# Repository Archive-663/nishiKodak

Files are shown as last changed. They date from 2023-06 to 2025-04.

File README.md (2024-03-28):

## Lot no. 006 | NishiKodak - The original digital stereoscopic wiggle lens

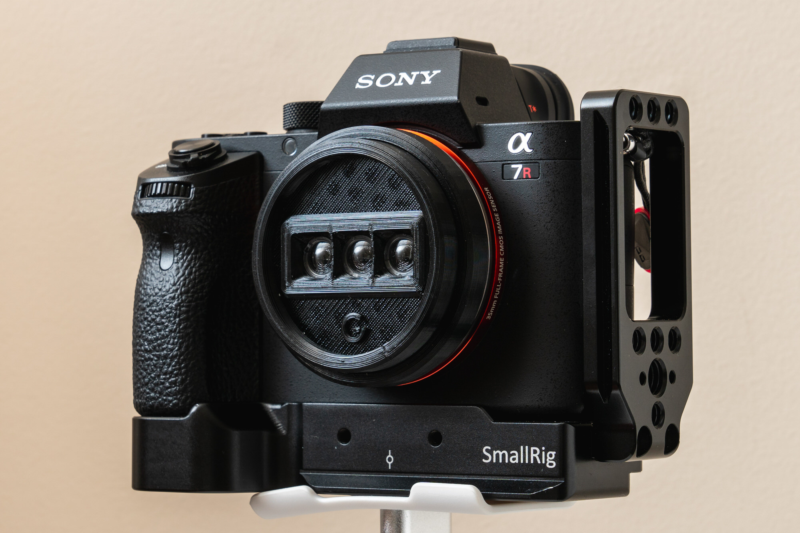
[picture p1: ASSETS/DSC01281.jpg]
sonyNishiKodak


### Features:
- Breech-lock mounting ring
- 30mm focal length
- Fixed ~f11 aperture
- Three individual images on one frame
- Available in: Canon EF, EF-S, FD, RF; Fuji X; Leica M; M42; Nikon F DX, F FX, Z FX; Sony E, FE

### What you'll need:
- Lots of M1.6 x 5mm pan head screws (PETG or ABS filament)
or
- Lots of M1.6 x 5mm self tapping screws (ABS filament)
- 1x M1.6 tap
- 3x Kodak Funsaver lenses (post-2015 expiration date. Kodak had a few lens changes in the Funsaver production lifetime. You'll need a recent Funsaver to make this work)

### What would be helpful:
- M1.4 drill bit
- M1.8/M2 drill bit

### Printing help:
I print with PETG because it's pretty easy to set up with and dial in. If you want to use something else, go for it. I'd stay away from PLA because it's not the best in heat and against solvents. 

Generally, my designs have chamfers on the print face of the STL.

Please view the printOrientation.3mf file for help with orienting the parts on the printer bed. 

### Assembly help:
I suggest drilling holds to their correct tap size before tapping. The M1.6 holes should be drilled out to 1.4mm then tapped with the M1.6 tap. The Rotator holes should be drilled out with an M2 or M1.8 drill bit.

When assembling the rotating assemblies use some synthetic grease similar to Super Lube PTFE or keycap lube to make the rotate function smoother.

Please view the _assembly.stp file for help in parts orientation. If you do not have a CAD program, <a href="https://www.freecad.org/downloads.php" target="_blank">download FreeCAD</a> to view the assembly file and better understand how it should assemble.

### Helpful videos:
- <a href="https://www.youtube.com/watch?v=ZdX-1SL8kYE" target="_blank">Old Print and Assembly Video</a>
- <a href="https://www.youtube.com/watch?v=JzHJL4l5Iv4" target="_blank">How to wigglegram</a>
- <a href="https://www.youtube.com/watch?v=mniP1P2PrpM" target="_blank">Kodak Funsaver Disassembly</a>
- <a href="https://www.youtube.com/watch?v=VX9ajfPWNos">How to use depth checker</a>

### Help support Archive 663 with a dontation or monthly sub



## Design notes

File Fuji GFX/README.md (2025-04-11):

## Lot no. 006 | NishiKodak - for Fuji GFX

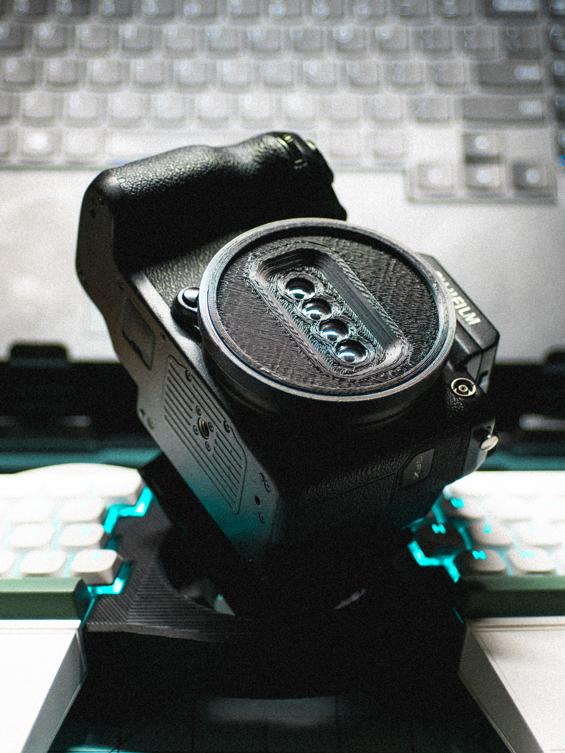
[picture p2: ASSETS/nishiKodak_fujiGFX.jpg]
nishiKodakforCanonEF


### Features:
- Breech-lock  mounting ring
- 30mm focal length
- Fixed ~f11 aperture
- Four individual images on one frame

### Compatibility Note:
Tested on Fuji GFX50s. Print the '_depthChecker.stl' to check for any intereference between the baffles and the shutter. To verify, with no lens mounted, fire the shutter. Make a note of where the mechanical shutter fires from. Mount the depth checker and visually inspect to verify the rear baffle doesn't interfere with the mechanical shutter. If you feel confident it doesn't fire the shutter to confirm. I recommend using the electronic shutter only to avoid any potential interfernce if you're not comfortable with firing the mechanical shutter. <a href="https://www.youtube.com/watch?v=VX9ajfPWNos" target="blank">How to use the Depth Checker</a>

### What you'll need:
- Lots of M1.6 x 5mm pan head screws (PETG or ABS filament)
  
  or

- Lots of M1.6 x 5mm self tapping screws (ABS filament)
- 1x M1.6 tap 
- 4x Kodak Funsaver lenses (post-2015 expiration date. Kodak had a few lens changes in the Funsaver production lifetime. You'll need a recent Funsaver to make this work)

### What would be helpful:
- M1.4 drill bit
- M1.8/M2 drill bit

### Printing help:
I print with PETG because it's pretty easy to set up with and dial in. If you want to use something else, go for it. I'd stay away from PLA because it's not the best in heat and against solvents. 

Generally, my designs have chamfers on the print face of the STL.

Please view the printOrientation.3mf file for help with orienting the parts on the printer bed. 

### Assembly help:
I suggest drilling holds to their correct tap size before tapping. The M1.6 holes should be drilled out to 1.4mm then tapped with the M1.6 tap.

When assembling the rotating assemblies use some synthetic grease similar to Super Lube PTFE or keycap lube to make the rotate function smoother.

Please view the _assembly.stp file for help in parts orientation. If you do not have a CAD program, <a href="https://www.freecad.org/downloads.php" target="_blank">download FreeCAD</a> to view the assembly file and better understand how it should assemble.

### Samples:

https://github.com/user-attachments/assets/031e57af-e085-4bb5-94cd-f6731c047f23

https://github.com/user-attachments/assets/eecb256a-fdc8-4389-a52b-32f700e525a3

https://github.com/user-attachments/assets/349b5d82-b2bf-4e74-a854-7cec7cf7e38c

https://github.com/user-attachments/assets/67260229-3af9-401f-a5c7-f7849224620d

https://github.com/user-attachments/assets/5532c04b-9abf-47cd-b237-354d25c75c0d

https://github.com/user-attachments/assets/e15609be-b9e9-426a-8cd3-ffbe995c0a97

https://github.com/user-attachments/assets/e63e4c56-d242-4f98-9afd-546e2806fb3d

https://github.com/user-attachments/assets/69e34002-13ab-48bc-9f69-8e1c6a932141

https://github.com/user-attachments/assets/c68fb221-d235-48c7-a15d-1476e1a5c071

https://github.com/user-attachments/assets/30f9192f-4e88-444a-a270-4611d918abf4

https://github.com/user-attachments/assets/bb41ffd1-9d08-4dcd-ba86-66c0b9891642

https://github.com/user-attachments/assets/c1f98dac-af3b-4983-9f93-2d6147c60b51

https://github.com/user-attachments/assets/950ef732-9b3b-4f6d-9e71-2f0eb0889de3

https://github.com/user-attachments/assets/1c553b8e-59a2-459e-8a27-6f503ef7dbbf

https://github.com/user-attachments/assets/238813ae-a682-4e9e-a184-02382c2696fb

https://github.com/user-attachments/assets/dc4757ad-16a0-45b5-9ce8-5064aa1b8b31

https://github.com/user-attachments/assets/94bc11c4-087a-428f-ba7e-fc0c8681b72b

https://github.com/user-attachments/assets/83f594a0-0b18-42b5-9fb1-5501689f5fb4

### Helpful videos:
- <a href="https://www.youtube.com/watch?v=ZdX-1SL8kYE" target="_blank">Old Print and Assembly Video</a>
- <a href="https://www.youtube.com/watch?v=JzHJL4l5Iv4" target="_blank">How to wigglegram</a>
- <a href="https://www.youtube.com/watch?v=mniP1P2PrpM" target="_blank">Kodak Funsaver Disassembly</a>

### Help support Archive 663 with a dontation or monthly sub



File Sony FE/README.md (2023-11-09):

## Lot no. 006 | NishiKodak - for Sony FE

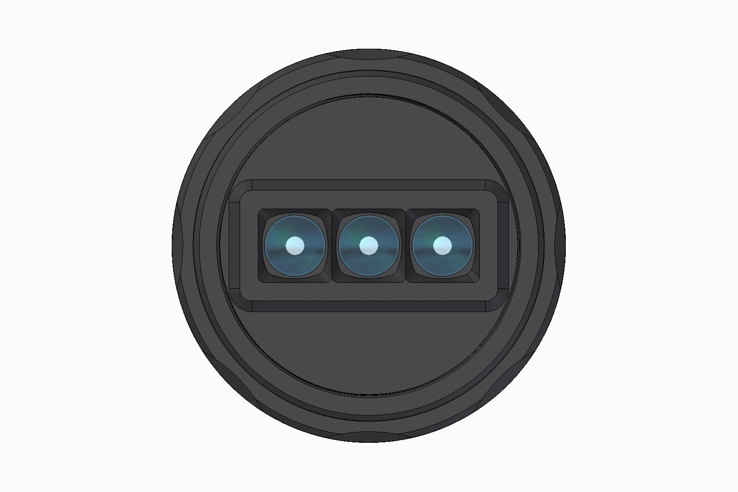
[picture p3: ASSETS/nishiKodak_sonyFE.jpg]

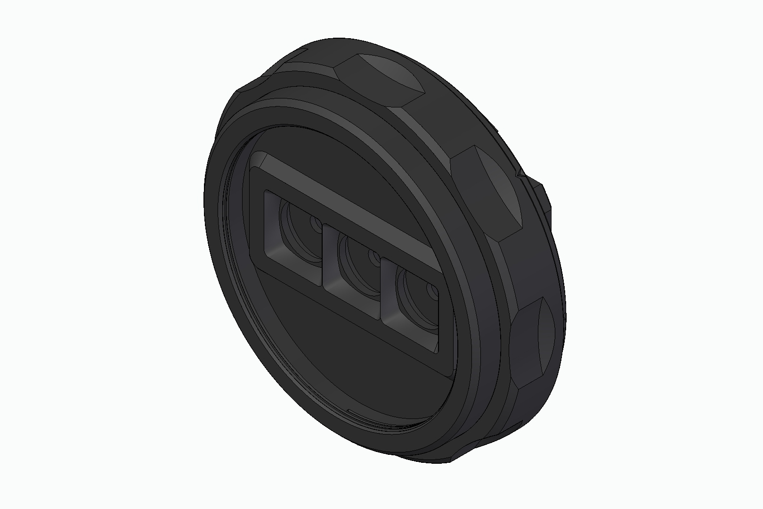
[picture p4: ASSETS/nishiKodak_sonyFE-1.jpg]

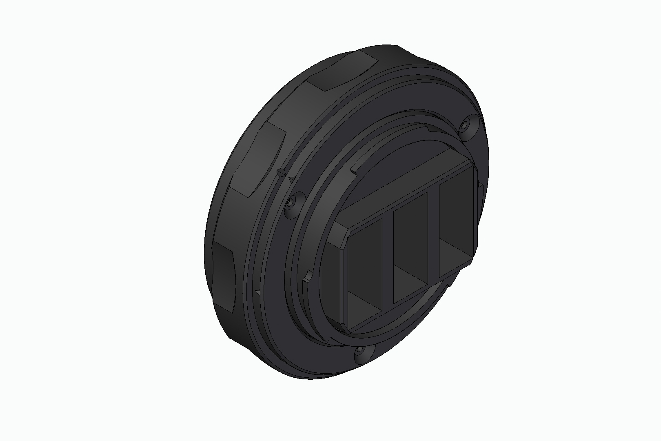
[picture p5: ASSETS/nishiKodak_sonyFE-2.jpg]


### Features:
- Breech-lock  mounting ring
- 30mm focal length
- Fixed ~f11 aperture
- Three individual images on one frame

### Compatibility Note:
Tested on A7RII. Print the '_depthChecker.stl' to check for any intereference between the baffles and the shutter. To verify, with no lens mounted, fire the shutter. Make a note of where the mechanical shutter fires from. Mount the depth checker and visually inspect to verify the rear baffle doesn't interfere with the mechanical shutter. If you feel confident it doesn't fire the shutter to confirm. I recommend using the electronic shutter only to avoid any potential interfernce if you're not comfortable with firing the mechanical shutter. 

### What you'll need:
- Lots of M1.6 x 5mm pan head screws (PETG or ABS filament)

  or

- Lots of M1.6 x 5mm self tapping screws (ABS filament)
- 1x M1.6 tap
- 3x Kodak Funsaver lenses (post-2015 expiration date. Kodak had a few lens changes in the Funsaver production lifetime. You'll need a recent Funsaver to make this work)

### What would be helpful:
- M1.4 drill bit
- M1.8/M2 drill bit

### Printing help:
I print with PETG because it's pretty easy to set up with and dial in. If you want to use something else, go for it. I'd stay away from PLA because it's not the best in heat and against solvents. 

Generally, my designs have chamfers on the print face of the STL.

Please view the printOrientation.3mf file for help with orienting the parts on the printer bed. 

### Assembly help:
I suggest drilling holds to their correct tap size before tapping. The M1.6 holes should be drilled out to 1.4mm then tapped with the M1.6 tap.

When assembling the rotating assemblies use some synthetic grease similar to Super Lube PTFE or keycap lube to make the rotate function smoother.

Please view the _assembly.stp file for help in parts orientation. If you do not have a CAD program, <a href="https://www.freecad.org/downloads.php" target="_blank">download FreeCAD</a> to view the assembly file and better understand how it should assemble.

### Samples:

Coming Soon.

### Helpful videos:
- <a href="https://www.youtube.com/watch?v=ZdX-1SL8kYE" target="_blank">Old Print and Assembly Video</a>
- <a href="https://www.youtube.com/watch?v=JzHJL4l5Iv4" target="_blank">How to wigglegram</a>
- <a href="https://www.youtube.com/watch?v=mniP1P2PrpM" target="_blank">Kodak Funsaver Disassembly</a>

### Help support Archive 663 with a dontation or monthly sub



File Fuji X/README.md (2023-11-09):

## Lot no. 006 | NishiKodak - for Fuji X

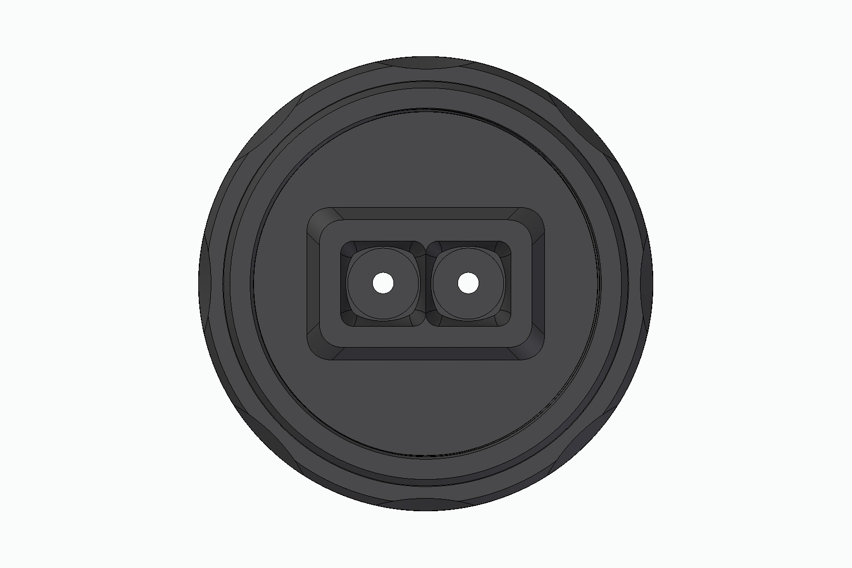
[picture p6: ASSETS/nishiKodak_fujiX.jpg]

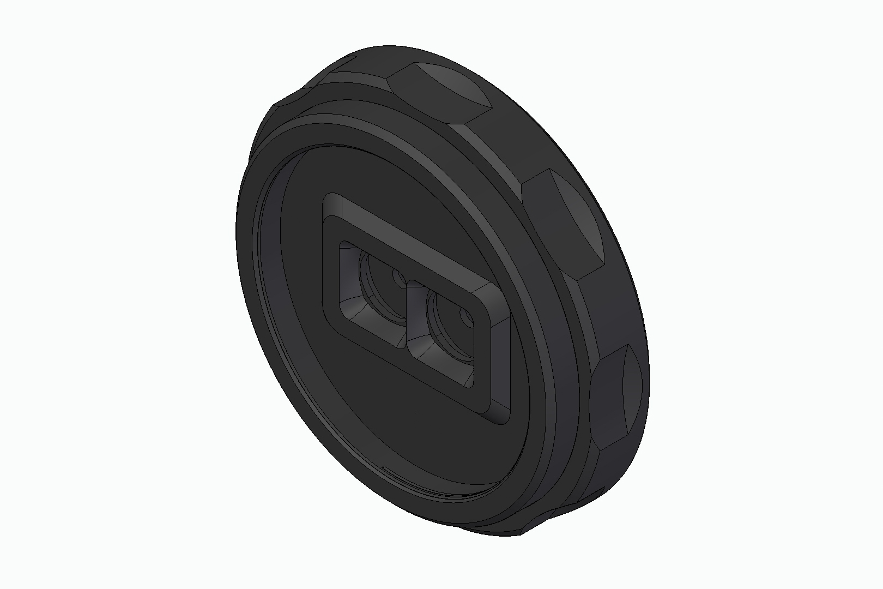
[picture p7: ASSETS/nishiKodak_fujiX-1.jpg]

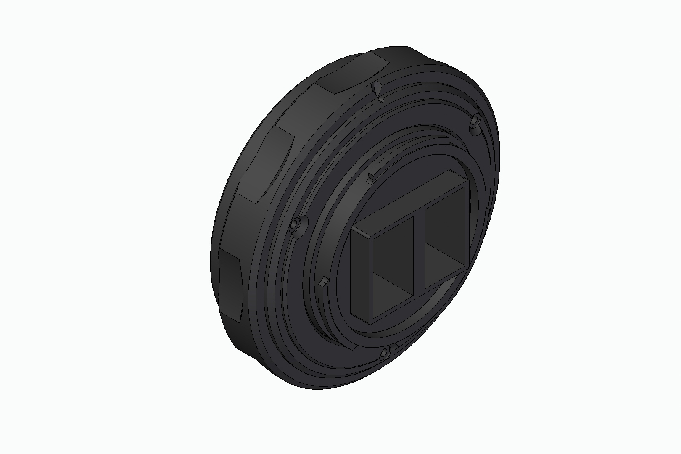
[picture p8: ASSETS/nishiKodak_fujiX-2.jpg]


### Features:
- Breech-lock  mounting ring
- 30mm focal length
- Fixed ~f11 aperture
- Two individual images on one frame

### Compatibility Note:
Tested on Fuji XE-1. Print the '_depthChecker.stl' to check for any intereference between the baffles and the shutter. To verify, with no lens mounted, fire the shutter. Make a note of where the mechanical shutter fires from. Mount the depth checker and visually inspect to verify the rear baffle doesn't interfere with the mechanical shutter. If you feel confident it doesn't fire the shutter to confirm. I recommend using the electronic shutter only to avoid any potential interfernce if you're not comfortable with firing the mechanical shutter. 

### What you'll need:
- Lots of M1.6 x 5mm pan head screws (PETG or ABS filament)
  
  or

- Lots of M1.6 x 5mm self tapping screws (ABS filament)
- 1x M1.6 tap 
- 2x Kodak Funsaver lenses (post-2015 expiration date. Kodak had a few lens changes in the Funsaver production lifetime. You'll need a recent Funsaver to make this work)

### What would be helpful:
- M1.4 drill bit
- M1.8/M2 drill bit

### Printing help:
I print with PETG because it's pretty easy to set up with and dial in. If you want to use something else, go for it. I'd stay away from PLA because it's not the best in heat and against solvents. 

Generally, my designs have chamfers on the print face of the STL.

Please view the printOrientation.3mf file for help with orienting the parts on the printer bed. 

### Assembly help:
I suggest drilling holds to their correct tap size before tapping. The M1.6 holes should be drilled out to 1.4mm then tapped with the M1.6 tap.

When assembling the rotating assemblies use some synthetic grease similar to Super Lube PTFE or keycap lube to make the rotate function smoother.

Please view the _assembly.stp file for help in parts orientation. If you do not have a CAD program, <a href="https://www.freecad.org/downloads.php" target="_blank">download FreeCAD</a> to view the assembly file and better understand how it should assemble.

### Samples:

Coming Soon.

### Helpful videos:
- <a href="https://www.youtube.com/watch?v=ZdX-1SL8kYE" target="_blank">Old Print and Assembly Video</a>
- <a href="https://www.youtube.com/watch?v=JzHJL4l5Iv4" target="_blank">How to wigglegram</a>
- <a href="https://www.youtube.com/watch?v=mniP1P2PrpM" target="_blank">Kodak Funsaver Disassembly</a>

### Help support Archive 663 with a dontation or monthly sub



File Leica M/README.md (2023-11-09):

## Lot no. 006 | NishiKodak - for Leica M

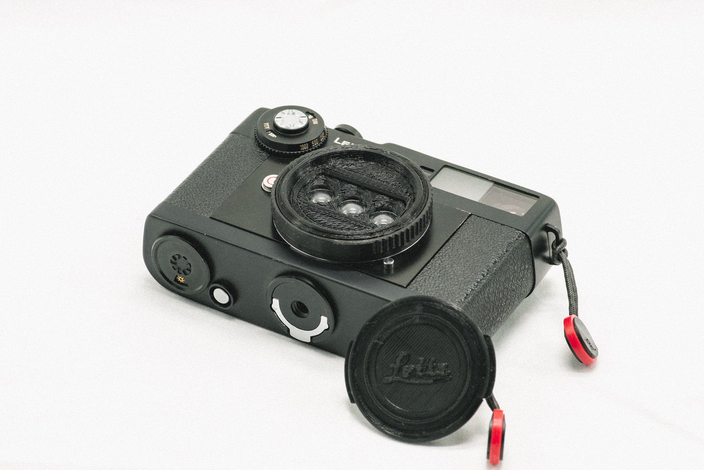
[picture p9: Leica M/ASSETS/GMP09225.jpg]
nishiKodakforLeicaM


### Features:
- Breech-lock  mounting ring
- 30mm focal length
- Fixed ~f11 aperture
- Three individual images on one frame

### Compatibility notes:
Tested on a Minolta CL. Print the '_depthChecker.stl' to check for any intereference between the baffles and the shutter. To verify, with no lens mounted, fire the shutter. Make a note of where the mechanical shutter fires from. Mount the depth checker and visually inspect to verify the rear baffle doesn't interfere with the mechanical shutter. If you feel confident it doesn't fire the shutter to confirm. 

### What you'll need:
- Lots of M1.6 x 5mm pan head screws (PETG or ABS filament)
  
  or

- Lots of M1.6 x 5mm self tapping screws (ABS filament)
- 1x M1.6 tap
- 3x Kodak Funsaver lenses (post-2015 expiration date. Kodak had a few lense changes in the Funsaver production lifetime. You'll need a recent Funsaver to make this work)
- <a href="https://github.com/Archive-663/kodakFunsaver/tree/main/DSLRviewFinder/STL">30mm Kodak Funsaver Viewfinder Rehousing</a>

### What would be helpful:
- M1.4 drill bit
- M1.8/M2 drill bit

### Printing help:
I print with PETG because it's pretty easy to set up with and dial in. If you want to use something else, go for it. I'd stay away from PLA because it's not the best in heat and against solvents. 

Generally, my designs have chamfers on the print face of the STL.

Please view the printOrientation.3mf file for help with orienting the parts on the printer bed. 

### Assembly help:
I suggest drilling holds to their correct tap size before tapping. The M1.6 holes should be drilled out to 1.4mm then tapped with the M1.6 tap.

When assembling the rotating assemblies use some synthetic grease similar to Super Lube PTFE or keycap lube to make the rotate function smoother.

Please view the _assembly.stp file for help in parts orientation. If you do not have a CAD program, <a href="https://www.freecad.org/downloads.php" target="_blank">download FreeCAD</a> to view the assembly file and better understand how it should assemble.

### Samples:

Raveena ATL concert | Pushed 800 to 3200, converted to black and white
FRAME001
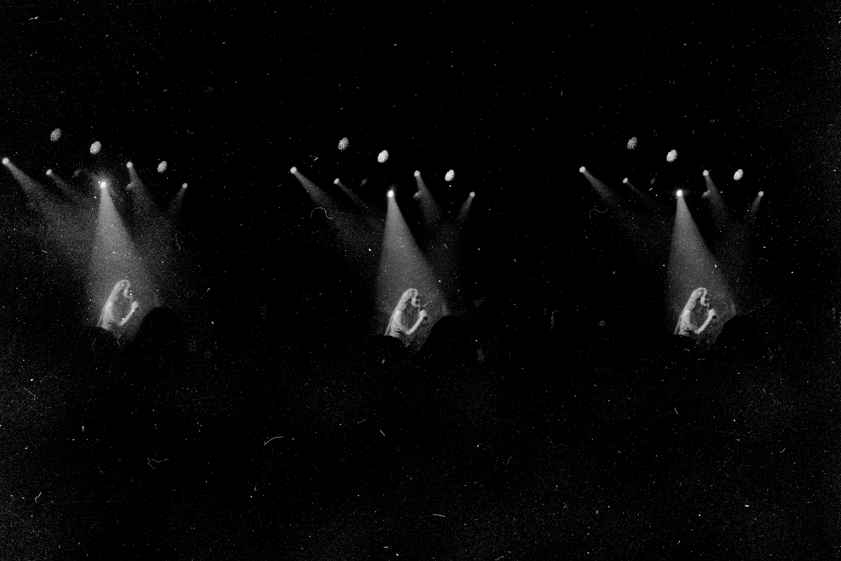
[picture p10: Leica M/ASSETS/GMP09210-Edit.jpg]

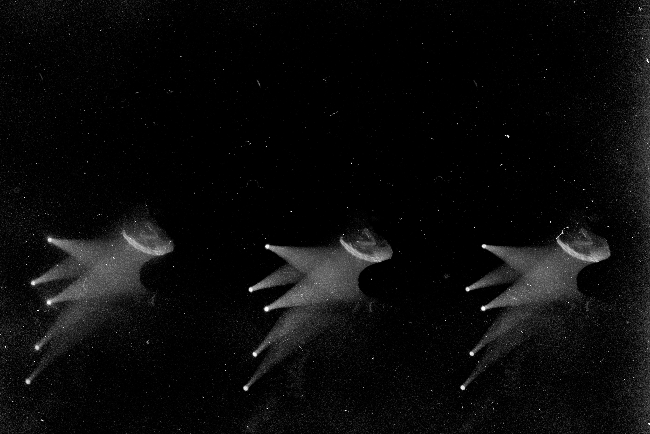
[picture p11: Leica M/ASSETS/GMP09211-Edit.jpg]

FRAME001
Sample001_LeicaM

### Helpful videos:
- <a href="https://www.youtube.com/watch?v=ZdX-1SL8kYE" target="_blank">Old Print and Assembly Video</a>
- <a href="https://www.youtube.com/watch?v=JzHJL4l5Iv4" target="_blank">How to wigglegram</a>
- <a href="https://www.youtube.com/watch?v=mniP1P2PrpM" target="_blank">Kodak Funsaver Disassembly</a>

### Help support Archive 663 with a dontation or monthly sub



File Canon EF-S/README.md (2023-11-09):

## Lot no. 006 | NishiKodak - for Canon EF-S

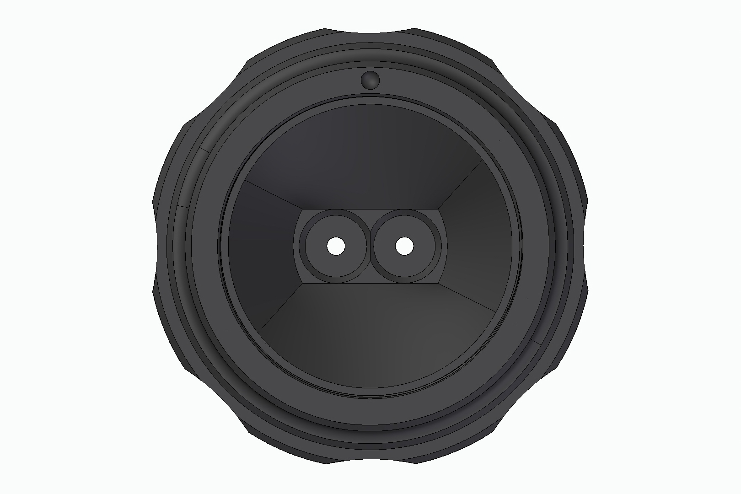
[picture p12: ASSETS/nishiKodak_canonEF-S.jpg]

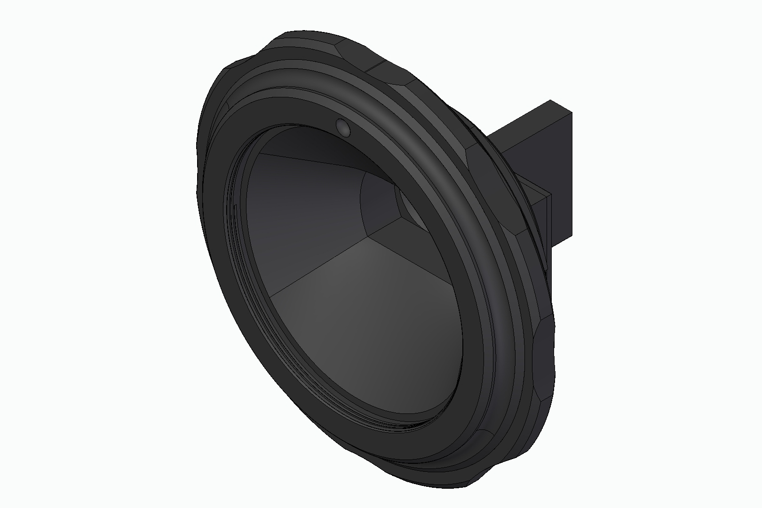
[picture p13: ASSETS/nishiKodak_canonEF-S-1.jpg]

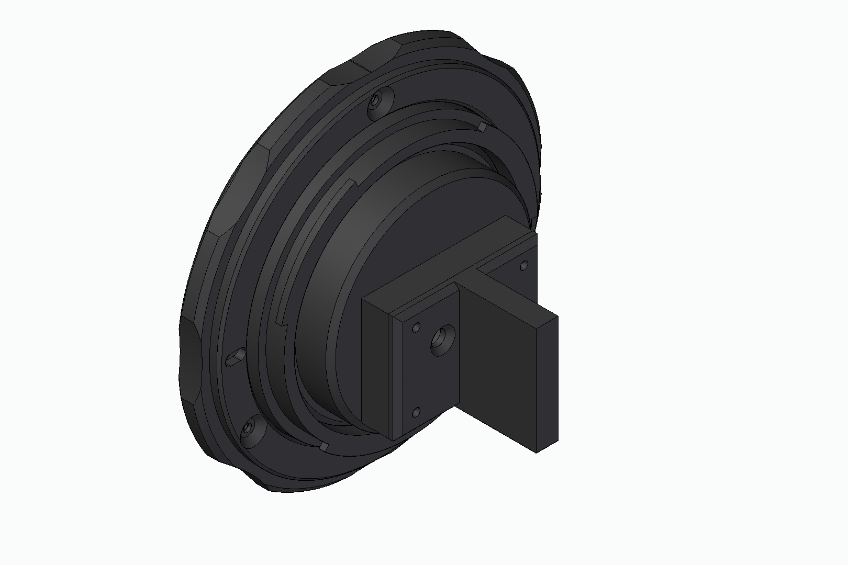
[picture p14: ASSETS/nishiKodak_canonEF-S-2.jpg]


### Features:
- Breech-lock  mounting ring
- 30mm focal length
- Fixed ~f11 aperture
- Two individual images on one frame

### Compatibility Note:
This lens doesn't work on the newer Canon 5D Mark IV, Canon 6D Mark II, and Canon 1DX series. The firmware on the 5D Mark IV and 6D Mark II both look for the mirror to make its full actuation before firing the shutter. This means we can lock the mirror with hardware to shoot with something like this lens. This lens isn't for the faint of heart, there is some risk of damaging your camera. Tested on a beaten old 5DC. Should work on film, but unconfirmed ATM -- will update. 

Tested on Canon XT + 5D Classic

### What you'll need:
- Lots of M1.6 x 5mm pan head screws (PETG or ABS filament)
  
  or

- Lots of M1.6 x 5mm self tapping screws (ABS filament)
- 1x M1.6 tap
- 2x Kodak Funsaver lenses (post-2015 expiration date. Kodak had a few lens changes in the Funsaver production lifetime. You'll need a recent Funsaver to make this work)
- <a href="https://github.com/Archive-663/kodakFunsaver/tree/main/DSLRviewFinder/STL">30mm Kodak Funsaver Viewfinder Rehousing</a>

### What would be helpful:
- M1.4 drill bit
- M1.8/M2 drill bit

### Printing help:
I print with PETG because it's pretty easy to set up with and dial in. If you want to use something else, go for it. I'd stay away from PLA because it's not the best in heat and against solvents. 

Generally, my designs have chamfers on the print face of the STL.

Please view the printOrientation.3mf file for help with orienting the parts on the printer bed. 

### Assembly help:
I suggest drilling holds to their correct tap size before tapping. The M1.6 holes should be drilled out to 1.4mm then tapped with the M1.6 tap.

When assembling the rotating assemblies use some synthetic grease similar to Super Lube PTFE or keycap lube to make the rotate function smoother.

Please view the _assembly.stp file for help in parts orientation. If you do not have a CAD program, <a href="https://www.freecad.org/downloads.php" target="_blank">download FreeCAD</a> to view the assembly file and better understand how it should assemble.

### Samples:

Coming Soon.

### Helpful videos:
- <a href="https://www.youtube.com/watch?v=ZdX-1SL8kYE" target="_blank">Old Print and Assembly Video</a>
- <a href="https://www.youtube.com/watch?v=JzHJL4l5Iv4" target="_blank">How to wigglegram</a>
- <a href="https://www.youtube.com/watch?v=mniP1P2PrpM" target="_blank">Kodak Funsaver Disassembly</a>

### Help support Archive 663 with a dontation or monthly sub



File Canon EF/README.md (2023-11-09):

## Lot no. 006 | NishiKodak - for Canon EF

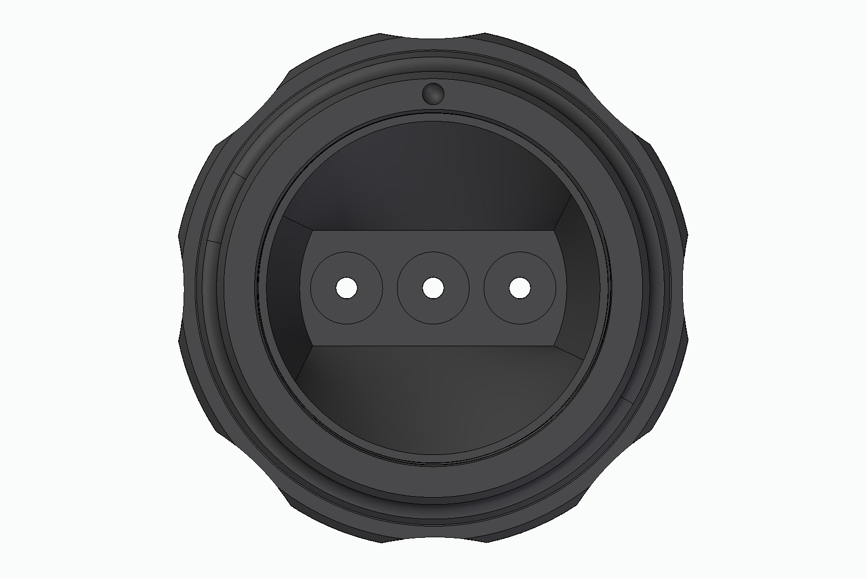
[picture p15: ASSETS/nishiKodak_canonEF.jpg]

nishiKodakforCanonEF
nishiKodakforCanonEF

### Features:
- Breech-lock  mounting ring
- 30mm focal length
- Fixed ~f11 aperture
- Three individual images on one frame

### Compatibility Note:
This lens doesn't work on the newer Canon 5D Mark IV, Canon 6D Mark II, and Canon 1DX series. The firmware on the 5D Mark IV and 6D Mark II both look for the mirror to make its full actuation before firing the shutter. This means we can lock the mirror with hardware to shoot with something like this lens. This lens isn't for the faint of heart, there is some risk of damaging your camera. Tested on a beaten old 5DC. Should work on film, but unconfirmed ATM -- will update. 

Tested on Canon XT + 5D Classic

### What you'll need:
- Lots of M1.6 x 5mm pan head screws (PETG or ABS filament)
  
  or

- Lots of M1.6 x 5mm self tapping screws (ABS filament)
- 1x M1.6 tap
- 3x Kodak Funsaver lenses (post-2015 expiration date. Kodak had a few lens changes in the Funsaver production lifetime. You'll need a recent Funsaver to make this work)
- <a href="https://github.com/Archive-663/kodakFunsaver/tree/main/DSLRviewFinder/STL">30mm Kodak Funsaver Viewfinder Rehousing</a>

### What would be helpful:
- M1.4 drill bit
- M1.8/M2 drill bit

### Printing help:
I print with PETG because it's pretty easy to set up with and dial in. If you want to use something else, go for it. I'd stay away from PLA because it's not the best in heat and against solvents. 

Generally, my designs have chamfers on the print face of the STL.

Please view the printOrientation.3mf file for help with orienting the parts on the printer bed. 

### Assembly help:
I suggest drilling holds to their correct tap size before tapping. The M1.6 holes should be drilled out to 1.4mm then tapped with the M1.6 tap.

When assembling the rotating assemblies use some synthetic grease similar to Super Lube PTFE or keycap lube to make the rotate function smoother.

Please view the _assembly.stp file for help in parts orientation. If you do not have a CAD program, <a href="https://www.freecad.org/downloads.php" target="_blank">download FreeCAD</a> to view the assembly file and better understand how it should assemble.

### Samples:

Coming Soon.

### Helpful videos:
- <a href="https://www.youtube.com/watch?v=ZdX-1SL8kYE" target="_blank">Old Print and Assembly Video</a>
- <a href="https://www.youtube.com/watch?v=JzHJL4l5Iv4" target="_blank">How to wigglegram</a>
- <a href="https://www.youtube.com/watch?v=mniP1P2PrpM" target="_blank">Kodak Funsaver Disassembly</a>

### Help support Archive 663 with a dontation or monthly sub



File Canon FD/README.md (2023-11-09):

## Lot no. 006 | NishiKodak - for Canon FD

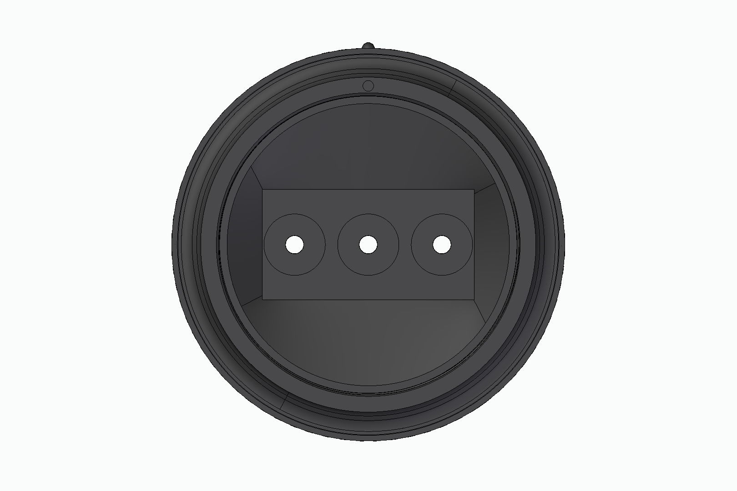
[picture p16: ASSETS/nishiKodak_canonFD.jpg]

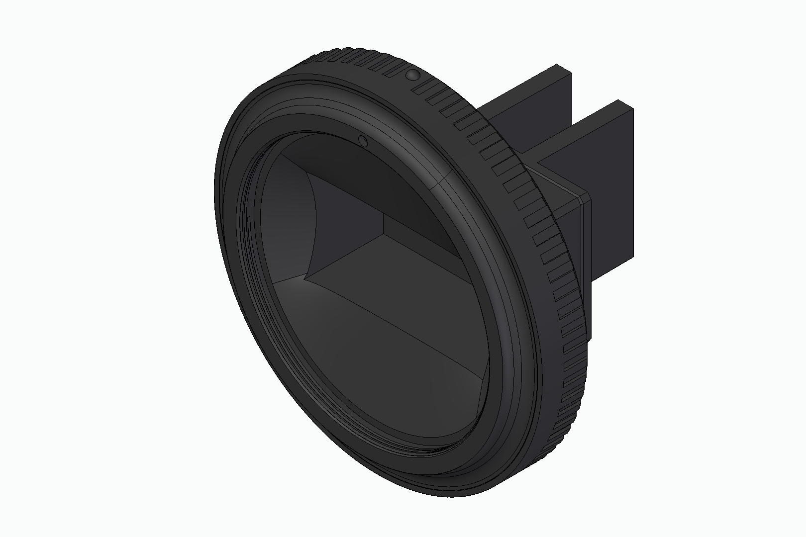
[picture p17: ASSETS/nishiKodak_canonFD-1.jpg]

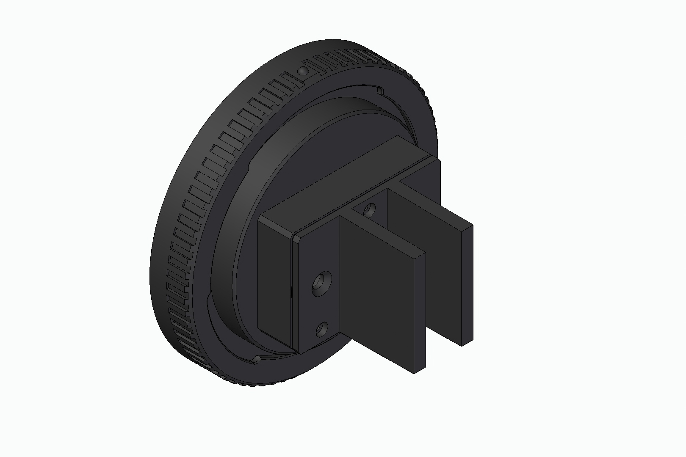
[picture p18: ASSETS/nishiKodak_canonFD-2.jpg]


### Features:
- Breech-lock  mounting ring
- 30mm focal length
- Fixed ~f11 aperture
- Three individual images on one frame

### Compatibility Note:
You need a Canon body that allows for mirror lock up. Some older film cameras allowed you to hold the mirror up with hardware, but there are some that link the mirror actuation to the shutter actuation so you can't lock your mirror up. Just make sure you have mirror lock up. Tested on a Canon FTb. 

### What you'll need:
- Lots of M1.6 x 5mm pan head screws (PETG or ABS filament)
  
  or

- Lots of M1.6 x 5mm self tapping screws (ABS filament)
- 1x M1.6 tap
- 1x M2 x 5mm Grub Screw 
- 3x Kodak Funsaver lenses (post-2015 expiration date. Kodak had a few lens changes in the Funsaver production lifetime. You'll need a recent Funsaver to make this work)
- <a href="https://github.com/Archive-663/kodakFunsaver/tree/main/DSLRviewFinder/STL">30mm Kodak Funsaver Viewfinder Rehousing</a>

### What would be helpful:
- M1.4 drill bit
- M1.8/M2 drill bit

### Printing help:
I print with PETG because it's pretty easy to set up with and dial in. If you want to use something else, go for it. I'd stay away from PLA because it's not the best in heat and against solvents. 

Generally, my designs have chamfers on the print face of the STL.

Please view the printOrientation.3mf file for help with orienting the parts on the printer bed. 

### Assembly help:
I suggest drilling holds to their correct tap size before tapping. The M1.6 holes should be drilled out to 1.4mm then tapped with the M1.6 tap.

When assembling the rotating assemblies use some synthetic grease similar to Super Lube PTFE or keycap lube to make the rotate function smoother.

Please view the _assembly.stp file for help in parts orientation. If you do not have a CAD program, <a href="https://www.freecad.org/downloads.php" target="_blank">download FreeCAD</a> to view the assembly file and better understand how it should assemble.

### Samples:

Coming Soon.

### Helpful videos:
- <a href="https://www.youtube.com/watch?v=ZdX-1SL8kYE" target="_blank">Old Print and Assembly Video</a>
- <a href="https://www.youtube.com/watch?v=JzHJL4l5Iv4" target="_blank">How to wigglegram</a>
- <a href="https://www.youtube.com/watch?v=mniP1P2PrpM" target="_blank">Kodak Funsaver Disassembly</a>

### Help support Archive 663 with a dontation or monthly sub



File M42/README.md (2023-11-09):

## Lot no. 006 | NishiKodak - for M42

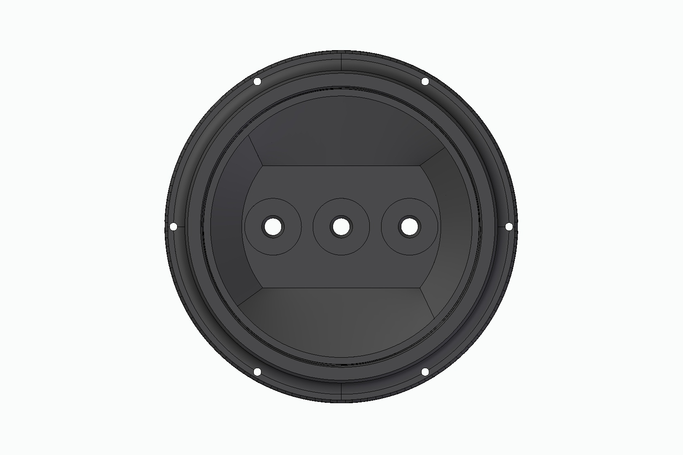
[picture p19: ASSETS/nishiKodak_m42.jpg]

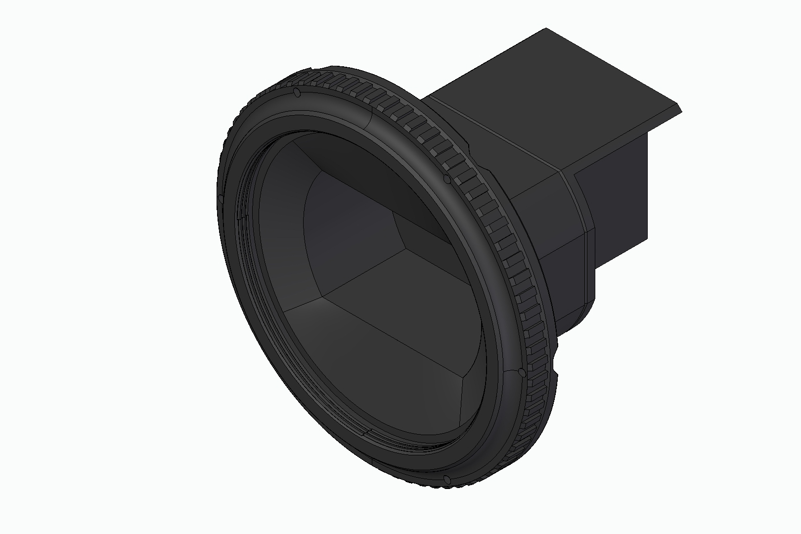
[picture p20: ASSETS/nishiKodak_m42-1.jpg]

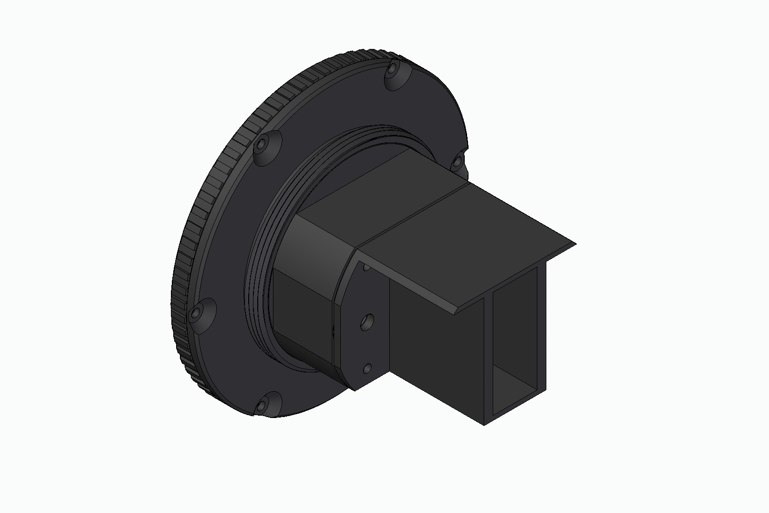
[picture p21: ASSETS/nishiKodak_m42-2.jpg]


### Features:
- Breech-lock  mounting ring
- 30mm focal length
- Fixed ~f11 aperture
- Three individual images on one frame

### Compatibility Note:
You need an M42 body that allows for mirror lock up. Some older film cameras allowed you to hold the mirror up with hardware, but there are some that link the mirror actuation to the shutter actuation so you can't lock your mirror up. Just make sure you have mirror lock up. Tested on a Sears/Ricoh TLS

### What you'll need:
- Lots of M1.6 x 5mm pan head screws (PETG or ABS filament)
  
  or

- Lots of M1.6 x 5mm self tapping screws (ABS filament)
- 1x M1.6 tap
- 3x Kodak Funsaver lenses (post-2015 expiration date. Kodak had a few lens changes in the Funsaver production lifetime. You'll need a recent Funsaver to make this work)
- <a href="https://github.com/Archive-663/kodakFunsaver/tree/main/DSLRviewFinder/STL">30mm Kodak Funsaver Viewfinder Rehousing</a>

### What would be helpful:
- M1.4 drill bit
- M1.8/M2 drill bit

### Printing help:
I print with PETG because it's pretty easy to set up with and dial in. If you want to use something else, go for it. I'd stay away from PLA because it's not the best in heat and against solvents. 

Generally, my designs have chamfers on the print face of the STL.

Please view the printOrientation.3mf file for help with orienting the parts on the printer bed. 

### Assembly help:
I suggest drilling holds to their correct tap size before tapping. The M1.6 holes should be drilled out to 1.4mm then tapped with the M1.6 tap.

When assembling the rotating assemblies use some synthetic grease similar to Super Lube PTFE or keycap lube to make the rotate function smoother.

Please view the _assembly.stp file for help in parts orientation. If you do not have a CAD program, <a href="https://www.freecad.org/downloads.php" target="_blank">download FreeCAD</a> to view the assembly file and better understand how it should assemble.

### Samples:

Coming Soon.

### Helpful videos:
- <a href="https://www.youtube.com/watch?v=ZdX-1SL8kYE" target="_blank">Old Print and Assembly Video</a>
- <a href="https://www.youtube.com/watch?v=JzHJL4l5Iv4" target="_blank">How to wigglegram</a>
- <a href="https://www.youtube.com/watch?v=mniP1P2PrpM" target="_blank">Kodak Funsaver Disassembly</a>

### Help support Archive 663 with a dontation or monthly sub



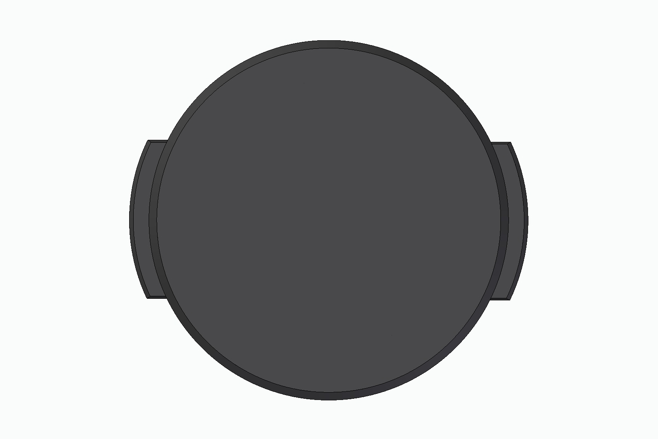
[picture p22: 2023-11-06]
ASSETS/lensCap_43mm.jpg

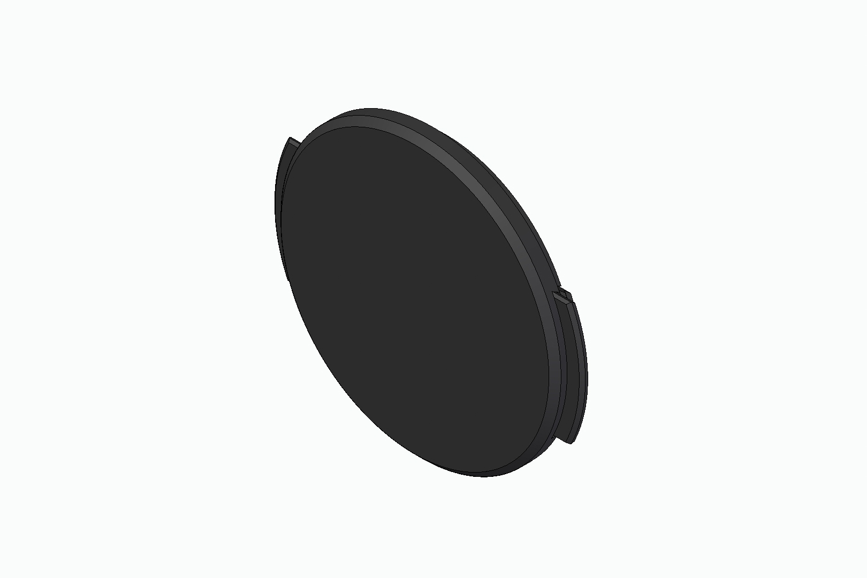
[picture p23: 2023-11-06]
ASSETS/lensCap_43mm-1.jpg

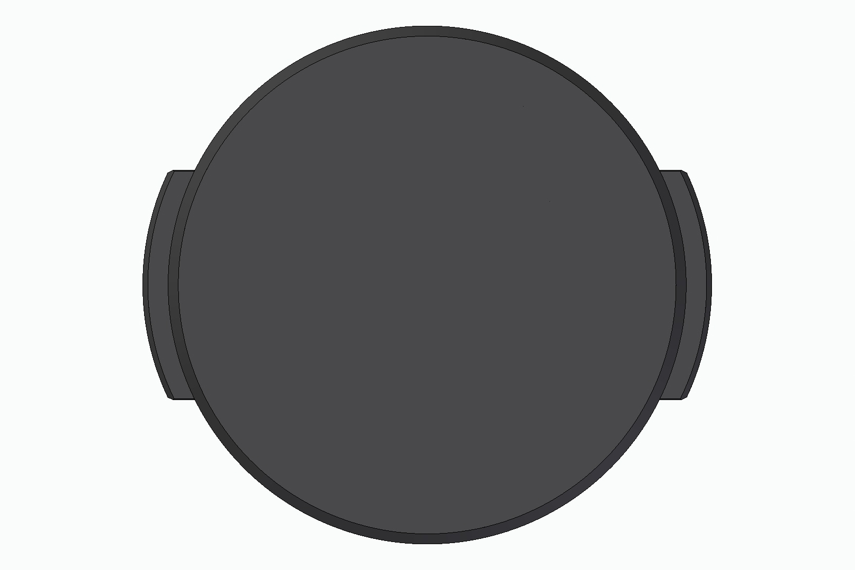
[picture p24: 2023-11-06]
ASSETS/lensCap_49mm.jpg

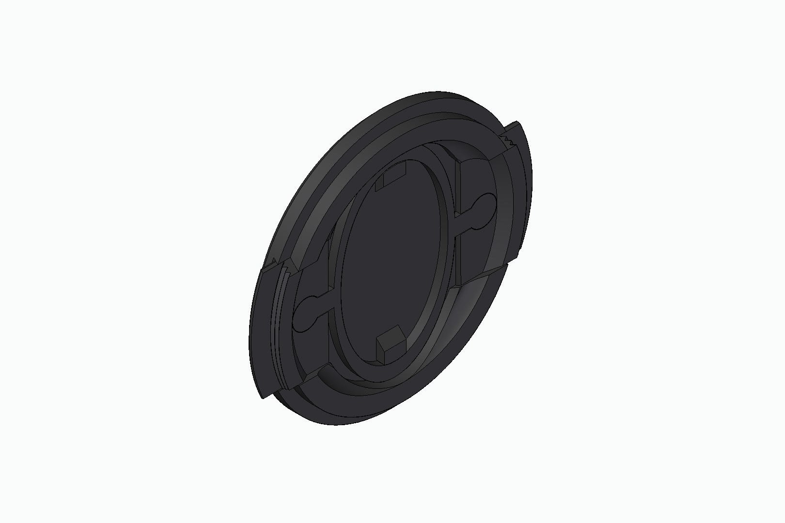
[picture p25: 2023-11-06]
ASSETS/lensCap_43mm-2.jpg

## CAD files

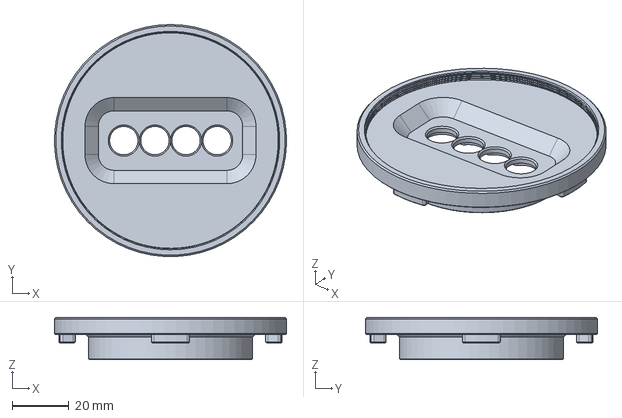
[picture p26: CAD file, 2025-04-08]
Fuji GFX/STEP/nishiKodak-fujiGFX_mainBody.stp
82.0 x 81.9 x 15.0 mm

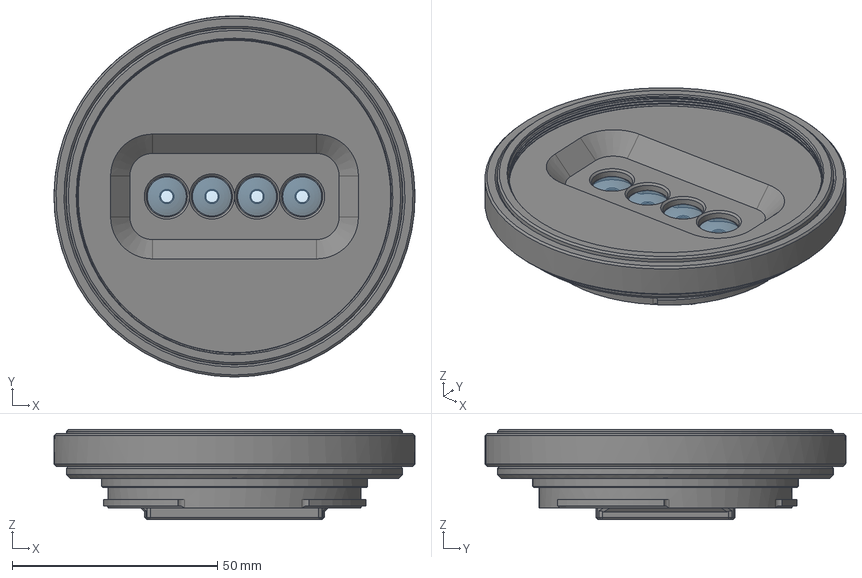
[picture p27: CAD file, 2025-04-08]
Fuji GFX/STEP/nishiKodak_fujiGFX_assembly.stp
88.0 x 88.0 x 22.0 mm
nishiKodak_30mmLens x 4
nishiKodak_GFX_mountFlange
nishiKodak_GFX_mountCap
M1.6_panHead_5mm x 8
nishiKodak_GFX_mountLockRing
nishiKodak_GFX_lensBaffle_short
nishiKodak_GFX_mainBody

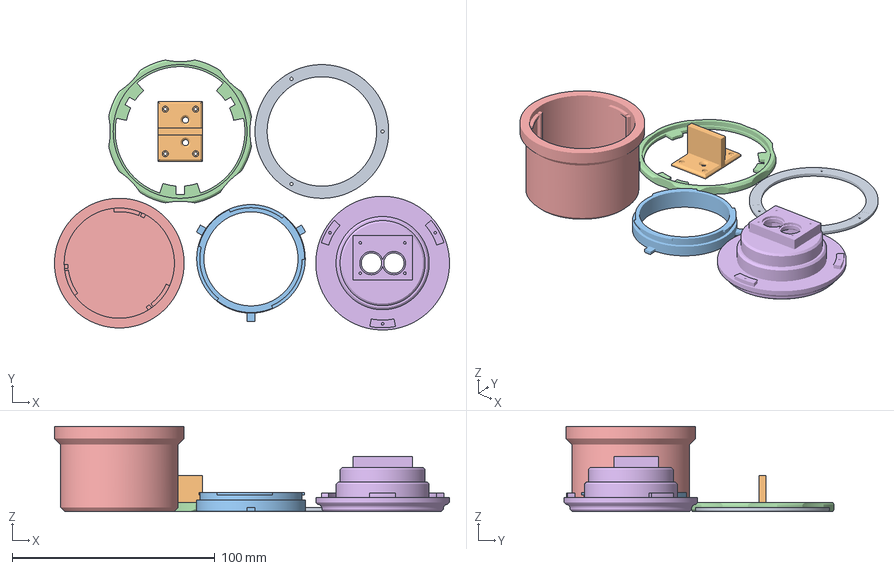
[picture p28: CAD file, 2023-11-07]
Canon EF-S/STL/printOrientation_nishiKodak_canonEF-S.3mf
195.0 x 133.3 x 42.0 mm
nishiKodak_canonEF_mountCap.stl
nishiKodak_canonEF-S_lensBaffle-3_5mm.stl
nishiKodak_canonEF_mountFlange.stl
nishiKodak_canonEF_mountLockRing.stl
nishiKodak_canonEF_rearCap.stl
nishiKodak_canonEF-S_lensBody.stl

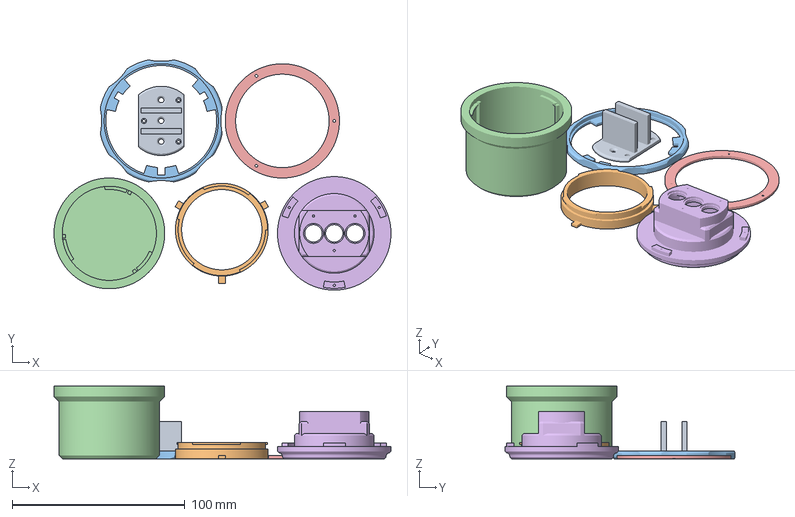
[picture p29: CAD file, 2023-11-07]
Canon EF/STL/printOrientation_nishiKodak_canonEF.3mf
194.8 x 133.1 x 42.0 mm
nishiKodak_canonEF_lensBaffle.stl
nishiKodak_canonEF_mountFlange.stl
nishiKodak_canonEF_mountLockRing.stl
nishiKodak_canonEF_rearCap.stl
nishiKodak_canonEF_mountCap.stl
nishiKodak_canonEF_lensBody.stl

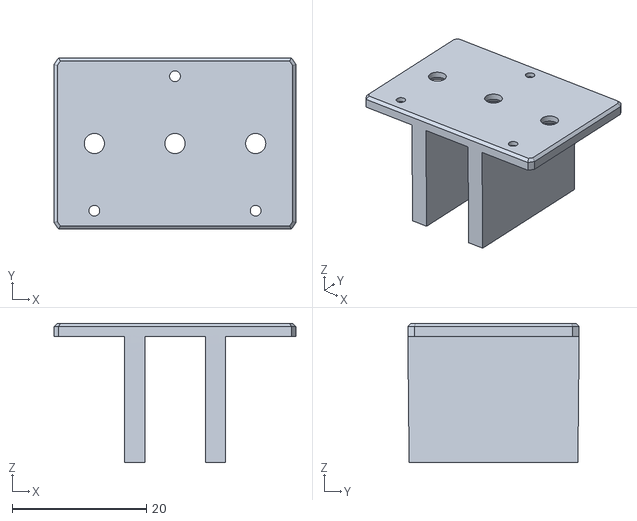
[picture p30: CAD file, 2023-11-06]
Canon FD/STL/nishiKodak_canonFD_lensBaffle.stl
36.0 x 25.5 x 20.7

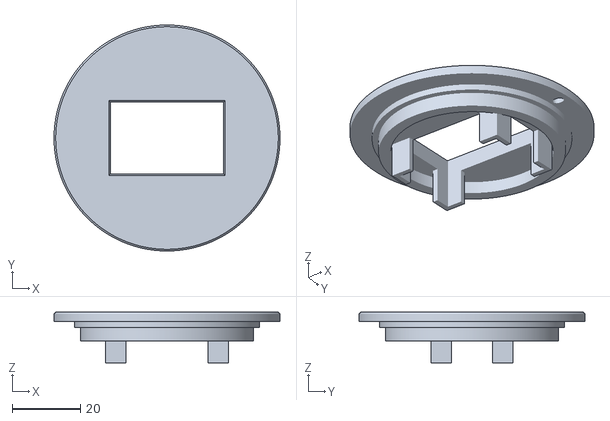
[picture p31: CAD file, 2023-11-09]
Canon RF/STL/nishiKodak_canonRF_depthChecker.stl
66.0 x 66.0 x 14.8

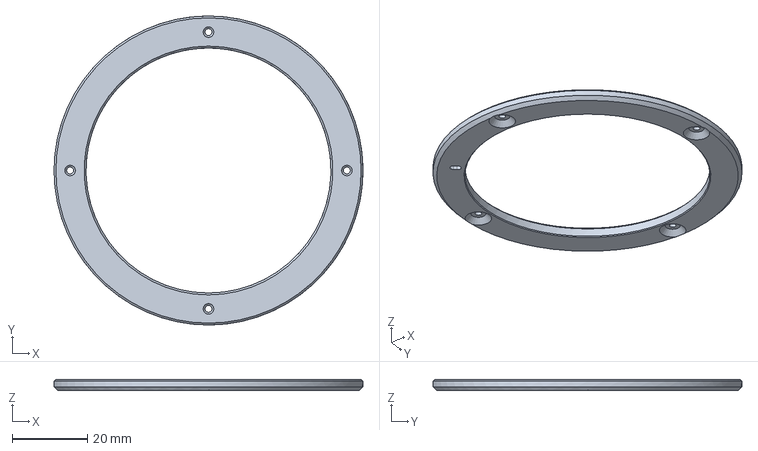
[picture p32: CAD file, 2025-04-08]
Fuji GFX/STEP/nishiKodak-fujiGFX_mountCap.stp
82.0 x 82.0 x 3.00 mm

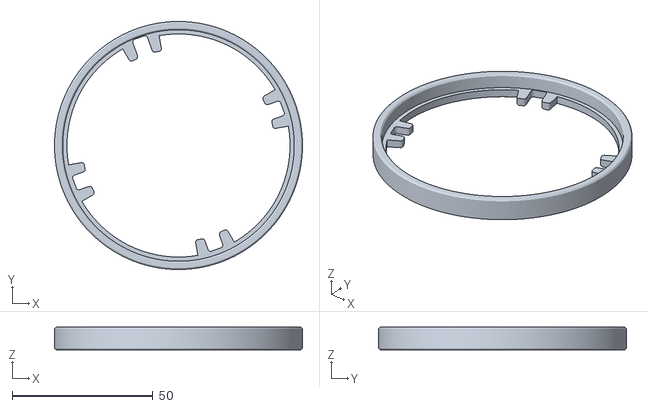
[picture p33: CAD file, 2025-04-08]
Fuji GFX/STL/nishiKodak_GFX_mountLockRing.stl
88.0 x 88.0 x 8.00

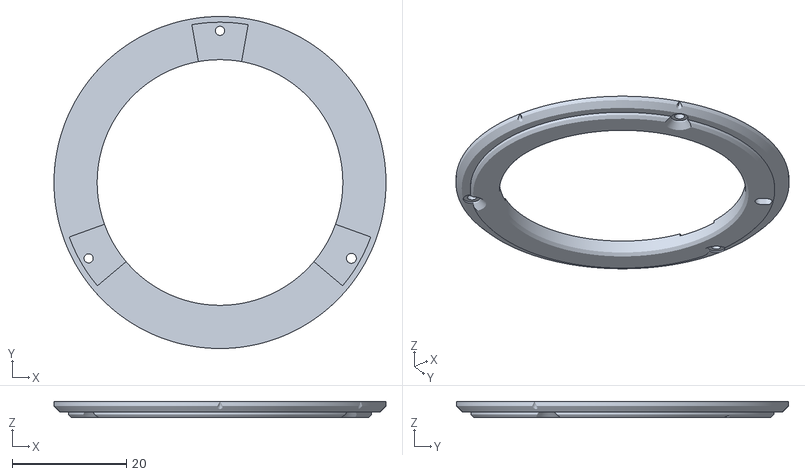
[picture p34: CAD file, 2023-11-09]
Fuji X/STL/nishiKodak_fujiX_mountCap.stl
58.0 x 58.0 x 2.80

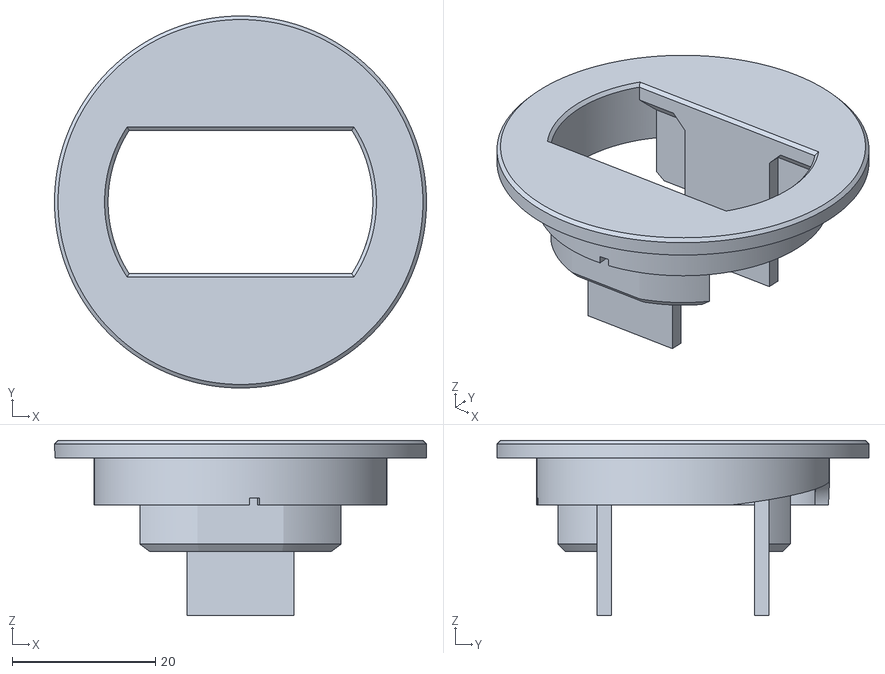
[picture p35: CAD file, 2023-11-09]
Leica M/STL/nishiKodak_leicaM_depthChecker.stl
52.0 x 52.0 x 24.5

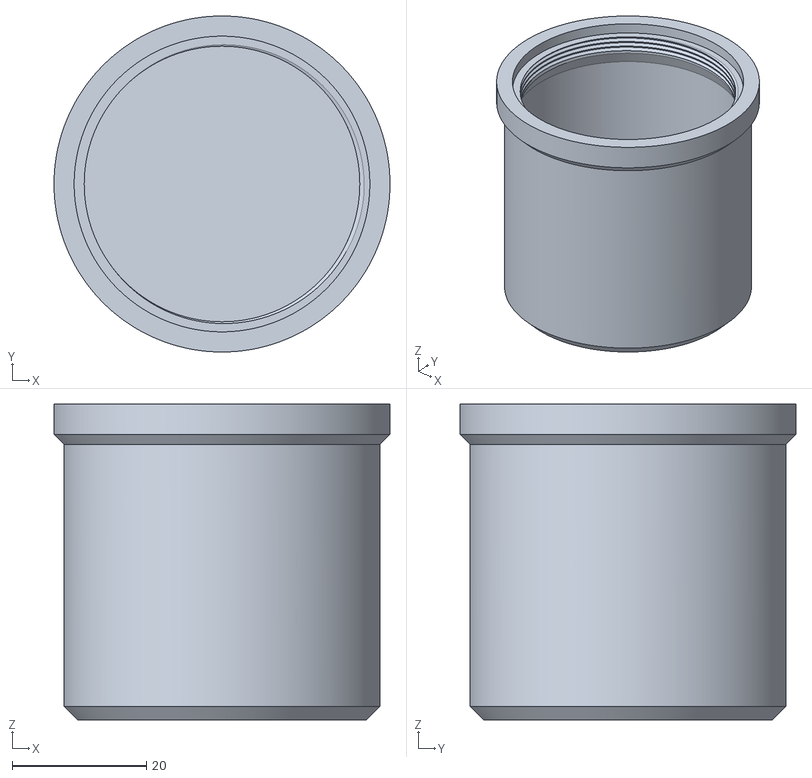
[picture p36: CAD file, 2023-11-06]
M42/STL/nishiKodak_M42_rearCap.stl
50.0 x 50.0 x 47.0

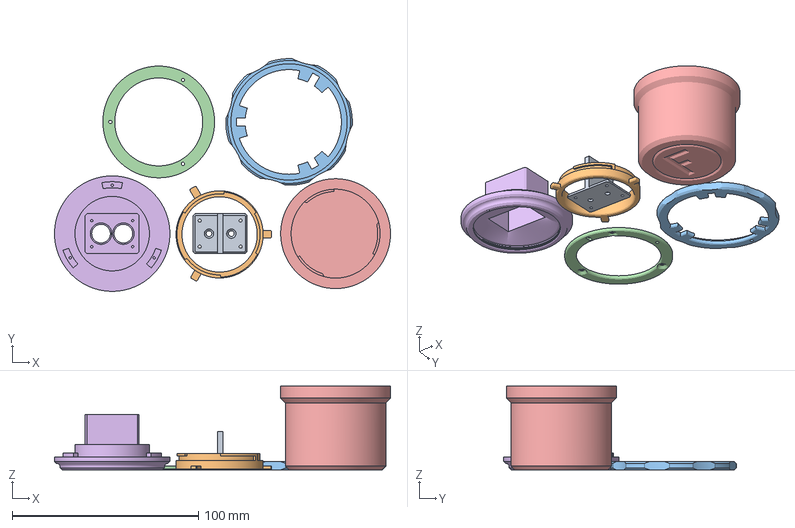
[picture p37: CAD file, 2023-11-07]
Nikon F DX/STL/printOrientation_nishiKodak_nikonF-DX.3mf
180.5 x 125.0 x 45.0 mm
nishiKodak_nikonF-DX_lensBaffle.stl
nishiKodak_nikonF-FX_mountFlange.stl
nishiKodak_nikonF-FX_mountLockRing.stl
nishiKodak_nikonF-FX_mountCap.stl
nishiKodak_nikonF-FX_rearCap.stl
nishiKodak_nikonF-DX_lensBody.stl

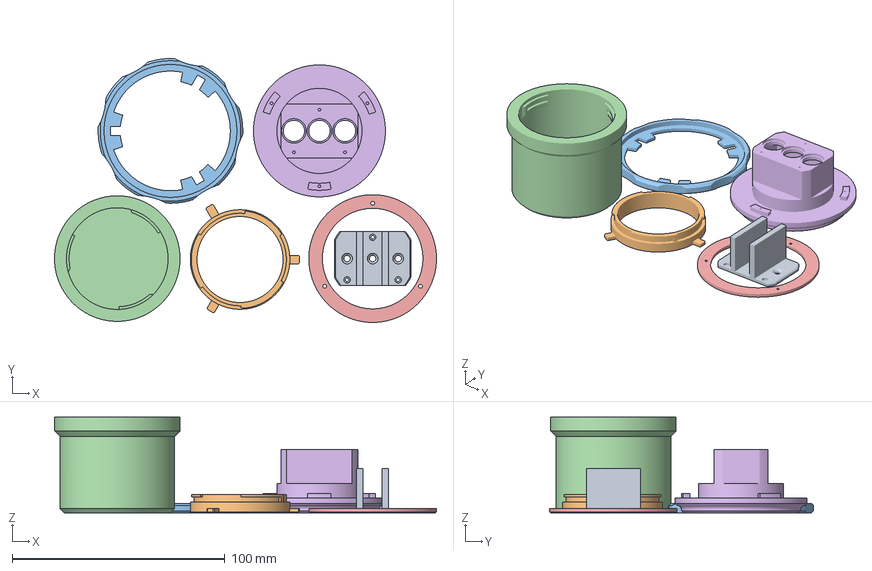
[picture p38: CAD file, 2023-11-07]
Nikon F FX/STL/printOrientation_nishiKodak_nikonF-FX.3mf
179.5 x 124.0 x 45.0 mm
nishiKodak_nikonF-FX_lensBaffle.stl
nishiKodak_nikonF-FX_mountFlange.stl
nishiKodak_nikonF-FX_mountLockRing.stl
nishiKodak_nikonF-FX_rearCap.stl
nishiKodak_nikonF-FX_mountCap.stl
nishiKodak_nikonF-FX_lensBody.stl

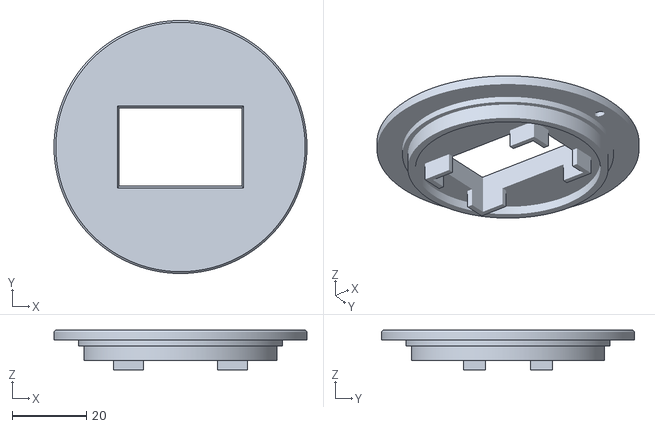
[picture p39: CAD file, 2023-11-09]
Nikon Z FX/STL/nishiKodak_nikonZ_depthChecker.stl
68.0 x 68.0 x 10.7

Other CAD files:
Fuji GFX/STL/nishiKodak_GFX_mainBody.stl
Sony E/STL/nishiKodak_sonyE_depthChecker.stl
Sony FE/STL/nishiKodak_sonyFE_depthChecker.stl
Canon EF-S/STL/nishiKodak_canonEF_rearCap.stl
Canon EF-S/STL/nishiKodak_canonEF-S_lensBaffle-3_5mm.stl
Canon EF-S/STL/nishiKodak_canonEF-S_lensBaffle-4_5mm.stl
Canon EF-S/STL/nishiKodak_canonEF_mountCap.stl
Canon EF-S/STL/nishiKodak_canonEF_mountFlange.stl
Canon EF-S/STL/nishiKodak_canonEF_mountLockRing.stl
Canon EF/STL/nishiKodak_canonEF_lensBaffle.stl
Canon EF/STL/nishiKodak_canonEF_mountCap.stl
Canon EF/STL/nishiKodak_canonEF_mountFlange.stl
Canon EF/STL/nishiKodak_canonEF_mountLockRing.stl
Canon EF/STL/nishiKodak_canonEF_rearCap.stl
Canon FD/STL/nishiKodak_canonFD_breechLock.stl
Canon FD/STL/nishiKodak_canonFD_rearCap.stl
Canon RF/STL/nishiKodak_canonRF_lensBaffle_long.stl
Canon RF/STL/nishiKodak_canonRF_lensBaffle_short.stl
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

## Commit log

2023-06-27 Create nishiKodak + Uploaded Leica M version
    [Wiggle Lens_43mm Lens Cap Body.step, Wiggle Lens_43mm Lens Cap Body.stl, Wiggle Lens_43mm Lens Cap Nameplate.step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]
2023-11-06 Added mounts
    Added Canon EF, EF-S, FD, RF; Fuji X; Leica M; M42; Nikon F DX, F FX, Z FX; Sony E, FE
    [Wiggle Lens_43mm Lens Cap Body.step, Wiggle Lens_43mm Lens Cap Body.stl, Wiggle Lens_43mm Lens Cap Nameplate.step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]
2023-11-07 Update all STLs
    [nishiKodak_fujiX_lensBody.stl, nishiKodak_fujiX_mountLockRing.stl, nishiKodak_leicaM_lensBody.stl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]
2023-11-07 Upload printOrientation Files for nishiKodak
    [printOrientation_nishiKodak_canonEF-S.3mf, printOrientation_nishiKodak_canonEF.3mf, printOrientation_nishiKodak_canonRF.3mf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]
2023-11-09 Update
    Updated FUJI X Mount Cap.
    Added Depth Checker for mirrorless cameras to check for interference with mechanical shutter. And one for Leica M
    [nishiKodak_canonRF_depthChecker.stl, nishiKodak_fujiX_depthChecker.stl, nishiKodak_fujiX_mountCap.stl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]
2025-04-08 upload GFX
    [fujiGFX_rearCap.stp, mountRearCapGFX.stl, nishiKodak-fujiGFX_lensBaffle_short.stp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]
2025-04-08 add gif samples
